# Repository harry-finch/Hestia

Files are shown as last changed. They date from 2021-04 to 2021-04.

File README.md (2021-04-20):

# Hestia
A battery powered WiFi temperature sensor. The name comes from the ancient greek goddess of the hearth.

Because of its rather simple function (showing the temperature), this board can also serve as a base for other IOT projects. It embeds many basic features:
- USB to UART (CH340G)
- Auto-reset for code upload
- Li-Ion battery management (MCP73831)
- Battery level indicator
- Load sharing between battery and USB
- ESP8266 minimal wiring

The schematic should be easily customizable for other projects.

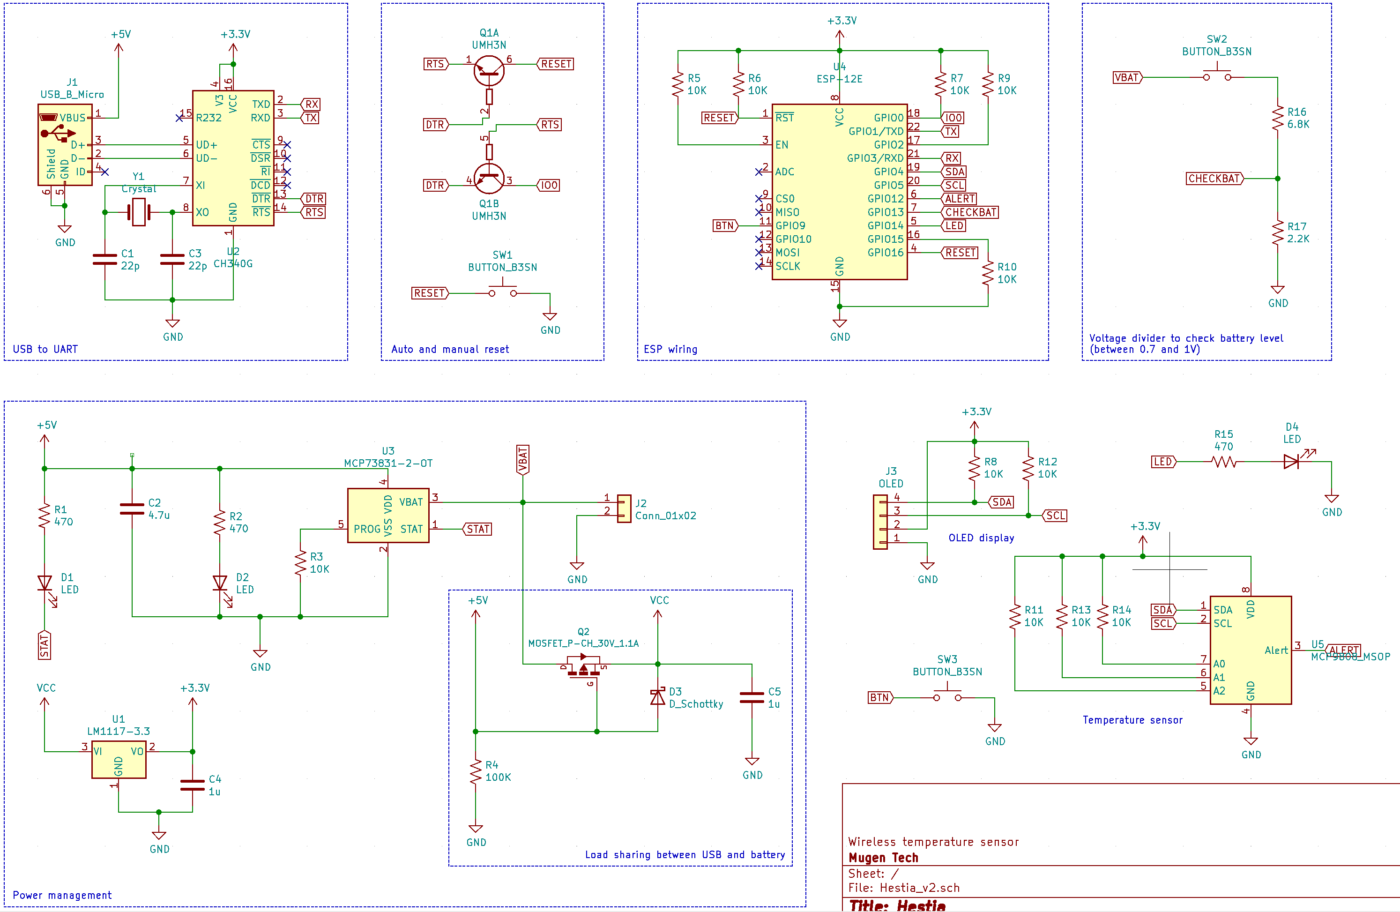
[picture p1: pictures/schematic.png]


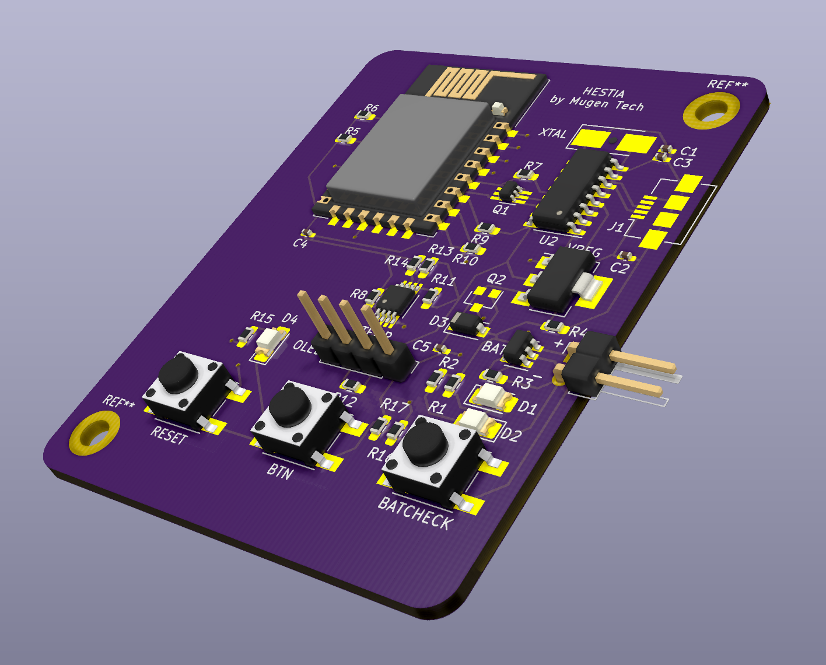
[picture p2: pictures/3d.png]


## Temperature sensor
This project uses the MCP9808 chip to measure the temperature. The reason for choosing this IC is because it uses I2C and will provide a more accurate reading than the MCU's ADC.

## Display
The board features 4 holes to wire a 0.91 inch OLED display. 

## Casing
The casing can be 3D printed.

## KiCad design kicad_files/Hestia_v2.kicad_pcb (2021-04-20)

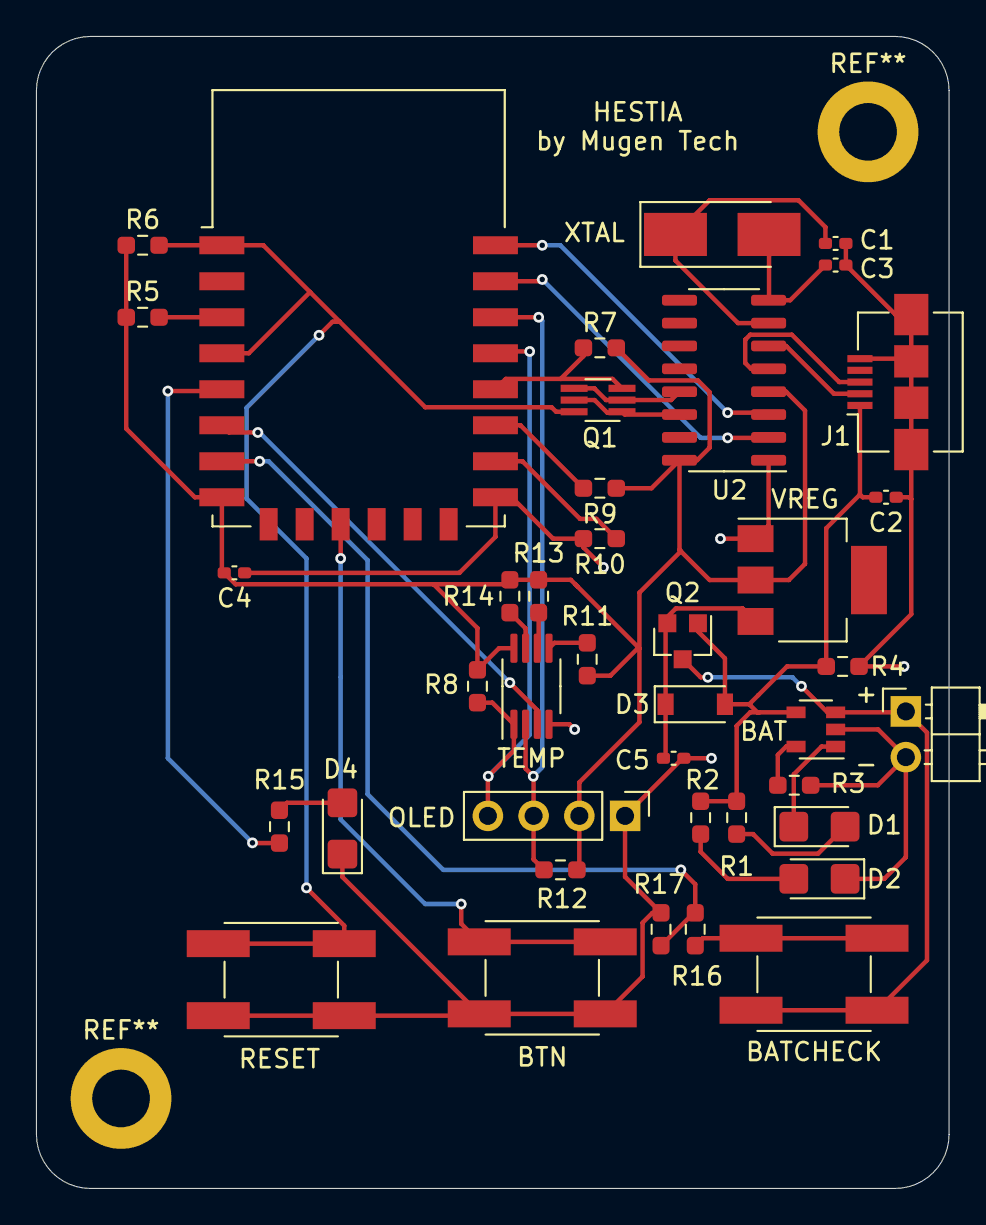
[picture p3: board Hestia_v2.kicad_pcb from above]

Board: 2 copper layers, 50.7 x 64.0 mm, 40 parts (0 on the bottom side), 33 nets.

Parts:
BAT: MCP73831-2-OT; SOT-23-5
BATCHECK: BUTTON_B3SN; Button_Omron_B3SN_6x6mm
BTN: BUTTON_B3SN; Button_Omron_B3SN_6x6mm
C1, C3: 22p; C_0402_1005Metric_Pad0.74x0.62mm_HandSolder
C2: 4.7u; C_0402_1005Metric_Pad0.74x0.62mm_HandSolder
C4, C5: 1u; C_0402_1005Metric_Pad0.74x0.62mm_HandSolder
D1, D2, D4: LED; LED_1206_3216Metric_Castellated
D3: D_Schottky; D_SOD-123
J1: USB_B_Micro; USB_Micro-B_Amphenol_10104110_Horizontal
J2: Conn_01x02; PinHeader_1x02_P2.54mm_Horizontal
OLED: OLED; PinHeader_1x04_P2.54mm_Vertical
Q1: UMH3N; SOT-363_SC-70-6_Handsoldering
Q2: MOSFET_P-CH_30V_1.1A; SOT-23
R1, R2, R15: 470; R_0603_1608Metric_Pad0.98x0.95mm_HandSolder
R3, R5, R6, R7, R8, R9, R10, R11, R12, R13, R14: 10K; R_0603_1608Metric_Pad0.98x0.95mm_HandSolder
R4: 100K; R_0603_1608Metric_Pad0.98x0.95mm_HandSolder
R16: 6.8K; R_0603_1608Metric_Pad0.98x0.95mm_HandSolder
R17: 2.2K; R_0603_1608Metric_Pad0.98x0.95mm_HandSolder
RESET: BUTTON_B3SN; Button_Omron_B3SN_6x6mm
TEMP: MCP9808_MSOP; MSOP-8_3x3mm_P0.65mm
U2: CH340G; SOIC-16_3.9x9.9mm_P1.27mm
U4: ESP-12E
VREG: LM1117-3.3; SOT-223
XTAL: Crystal; Crystal_SMD_5032-2Pin_5.0x3.2mm_HandSoldering

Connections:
+3V3: C4.1, OLED.2, R5.1, R6.1, R7.1, R8.2, R9.1, R11.2, R12.2, R13.2, R14.2, TEMP.8, U2.4, U2.16, U4.8, VREG.2
+5V: BAT.4, C2.1, D3.2, J1.1, Q2.1, R1.1, R2.1, R4.2
ALERT: TEMP.3, U4.6
BTN: BTN.1, U4.11
CHECKBAT: R16.2, R17.1, U4.7
DTR: Q1.2, Q1.4, U2.13
GND: BAT.2, BTN.2, C1.2, C2.2, C3.2, C4.2, C5.2, D2.1, D4.1, J1.5, J1.6, J2.2, OLED.1, R3.2, R4.1, R10.2, R17.2, RESET.2, TEMP.4, U2.1, U4.15, VREG.1
IO0: Q1.3, R7.2, U4.18
LED: R15.2, U4.5
unnamed: C1.1, U2.7, XTAL.1
unnamed: C3.1, U2.8, XTAL.2
unnamed: D1.2, R1.2
unnamed: D2.2, R2.2
unnamed: D4.2, R15.1
unnamed: J1.2, U2.6
unnamed: J1.3, U2.5
unnamed: BAT.5, R3.1
unnamed: R5.2, U4.3
unnamed: R9.2, U4.17
unnamed: R10.1, U4.16
unnamed: R11.1, TEMP.5
unnamed: R13.1, TEMP.6
unnamed: R14.1, TEMP.7
unnamed: BATCHECK.2, R16.1
RESET: Q1.6, R6.2, RESET.1, U4.1, U4.4
RTS: Q1.1, Q1.5, U2.14
RX: U2.2, U4.21
SCL: OLED.3, R12.1, TEMP.2, U4.20
SDA: OLED.4, R8.1, TEMP.1, U4.19
STAT: BAT.1, D1.1
TX: U2.3, U4.22
VBAT: BAT.3, BATCHECK.1, J2.1, Q2.3
VCC: C5.1, D3.1, Q2.2, VREG.3
